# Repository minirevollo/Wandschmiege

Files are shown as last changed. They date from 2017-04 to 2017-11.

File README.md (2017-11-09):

## Anreisswerkzeug

Mess- und Anzeichenwerkzeug zum Verlegen von Parkett, Laminat und Bodenplatten etc.

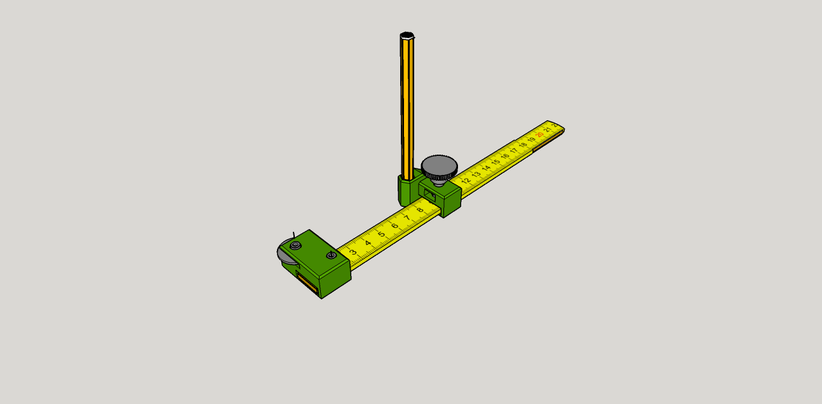
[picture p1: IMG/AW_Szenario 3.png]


Bestehend aus 3D-druckbaren Teilen und Standartelementen.

# Design #
Mit Sketchup konstruiert und als STL exportiert. Ziel war es ein Werkzeug zu erstellen, dass überwiegend mit Serienteilen zu produzieren ist und nur zwei Teile gedruckt werden müssen. Wer keinen 3D Drucker hat kommt einfach mal in den erfindergarden und wir helfen ihm weiter.
# Druck #
Slicen mit Craftware und Druck auf einem Craftbot
# Produktionsort #

[www.erfindergarden.de](http://www.erfindergarden.de)  , das Fab Lab in der Au - München
# Funktion #
Die Funktion ist auf dem folgenden Bild erklärt:

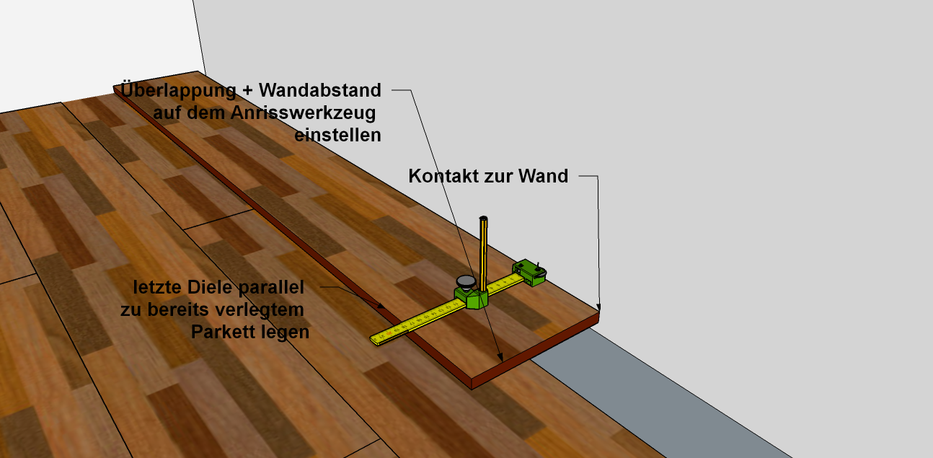
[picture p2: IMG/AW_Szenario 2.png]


Man legt die letzte Diele parallel zur vorletzten Diele und verschiebt sie dann parallel bis an die Wand. Dann misst man die Überlappung der beiden Dielen. Zu dieser Überlappung rechnet man noch den gewünschten Wandabstand (in der Regel 1 cm). Diese Summe stellt man auf dem Werkzeug ein. Nun fährt man mit dem Anreisser im rechten Winkel zur Wand an der Wand entlang und zeichnet dabei die Schnittlinie mit einem Bleistift an. Jetzt muss man nur noch mit einer Stichsäge und ruhiger Hand an der Linie entlang schneiden und die lezte Diele passt perfekt.

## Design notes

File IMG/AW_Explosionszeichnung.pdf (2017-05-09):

# Anreisswerkzeug

# ein Produkt aus dem erfindergarden (https://www.erfindergarden.de/) von

Andreas Reheis 2017 ,

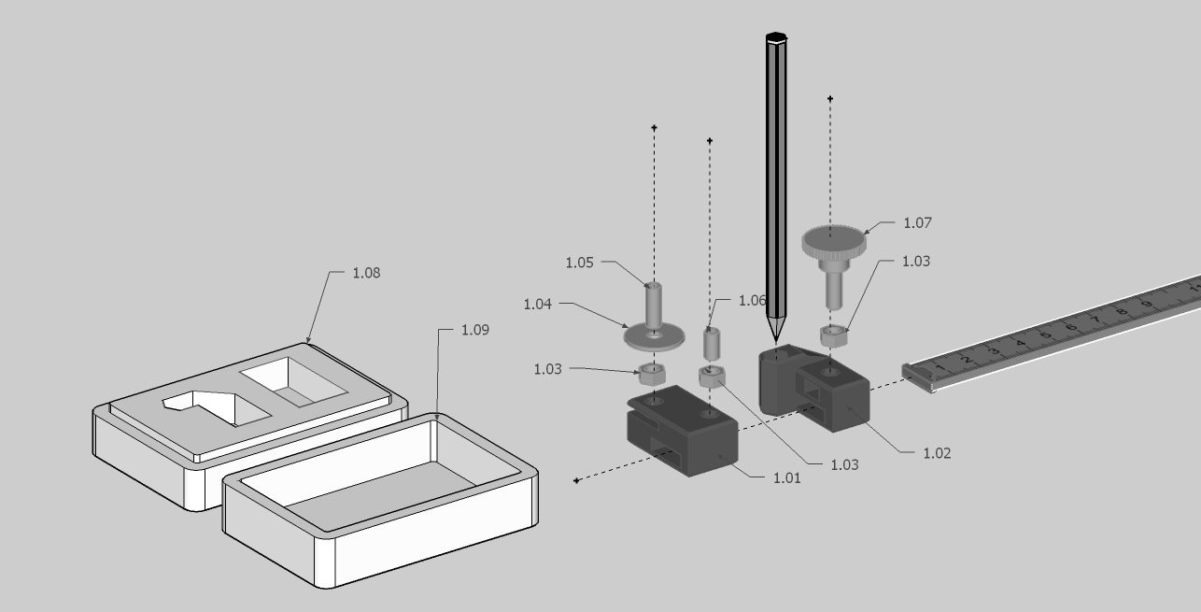
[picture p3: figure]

Teile Nr. | Beschreibung | Bezugsquelle
1.01 | Rollenhalter | Github (https://github.com/minirevollo/Wandschmiege/blob/master/AW_Rollenhalter%20v5.stl)
1.02 | Stifthalter | Github (https://github.com/minirevollo/Wandschmiege/blob/master/AW_Stifthalter_v5.stl)
1.03 | Mutter M5 | https://www.normschrauben.de/muttern/sechskant-muttern/sechskantmutter-sechskantmuttern-stahl-zn-934.html
1.04 | Beilagscheibe 20/6 | https://www.normschrauben.de/scheiben-beilagscheiben/din-9021-grosse-scheiben/scheiben-beilagscheiben-din-9021-verzinkt.html
1.05 | Madenschraube M5-15 | https://www.normschrauben.de/gewindestifte/gewindestifte-madenschrauben-din-914-stahl-blank.html
1.06 | Madenschraube M5-10 | https://www.normschrauben.de/gewindestifte/gewindestifte-madenschrauben-din-914-stahl-blank.html
1.07 | Rendelschraube M5-12 | https://www.befestigungsfuchs.de/befestigungstechnik/schrauben/raendelschrauben/10-raendelschrauben-m5-x-16-mm---din-653---niedrige-form---edelstahl-a1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
1.08 | Case Unterteil | Github (https://github.com/minirevollo/Wandschmiege/blob/master/AW_Case_Unterteil.stl)
1.09 | Case Oberteil | Github (https://github.com/minirevollo/Wandschmiege/blob/master/AW_Case_Oberteil.stl)

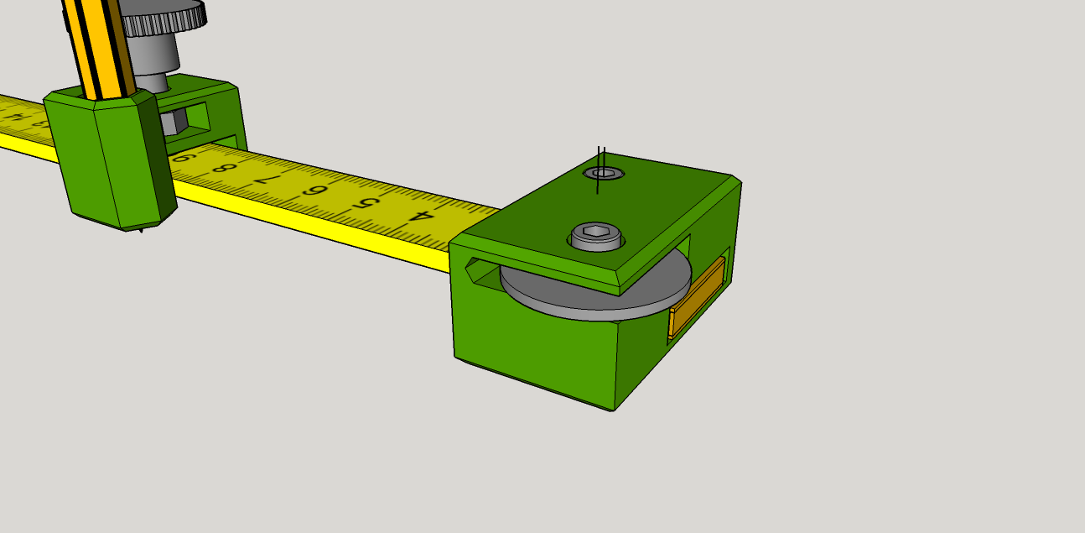
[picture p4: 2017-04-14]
IMG/AW_Szenario 4.png

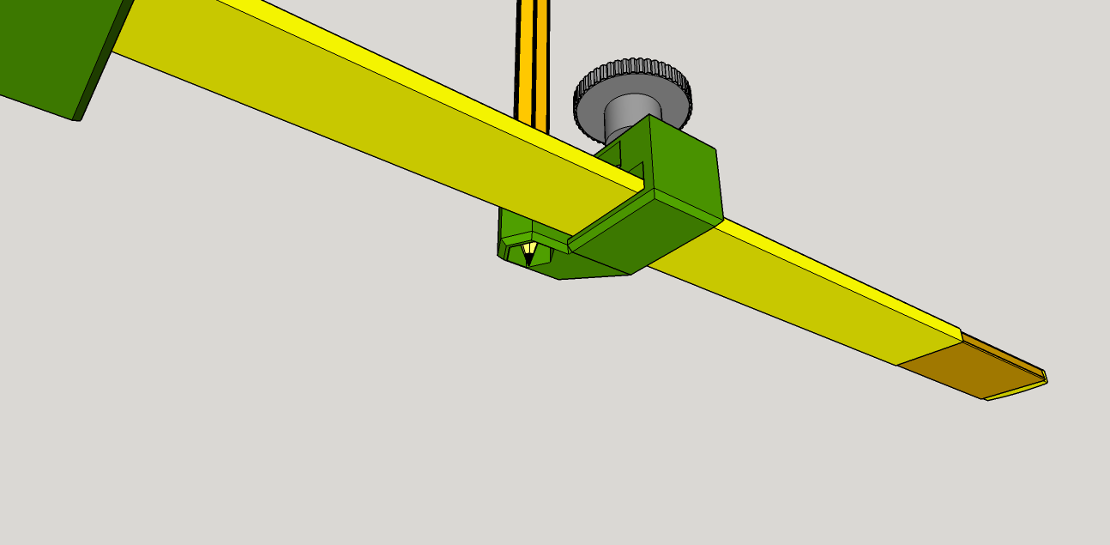
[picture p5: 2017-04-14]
IMG/AW_Szenario 5.png

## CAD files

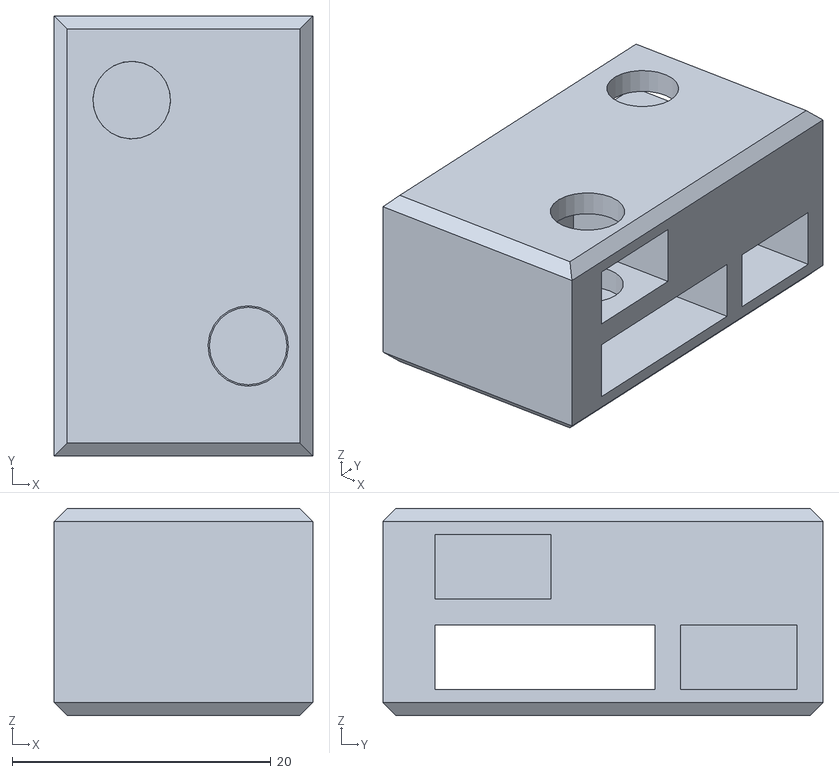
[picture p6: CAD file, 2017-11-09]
3D/AW_Rollenhalter v5.stl
20.0 x 34.0 x 16.0

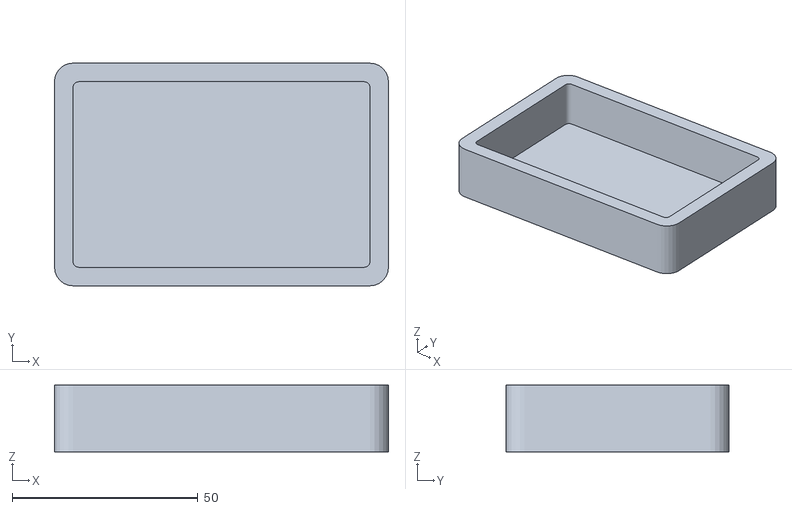
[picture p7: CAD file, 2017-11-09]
3D/AW_Case_Oberteil.stl
90.0 x 60.0 x 18.0

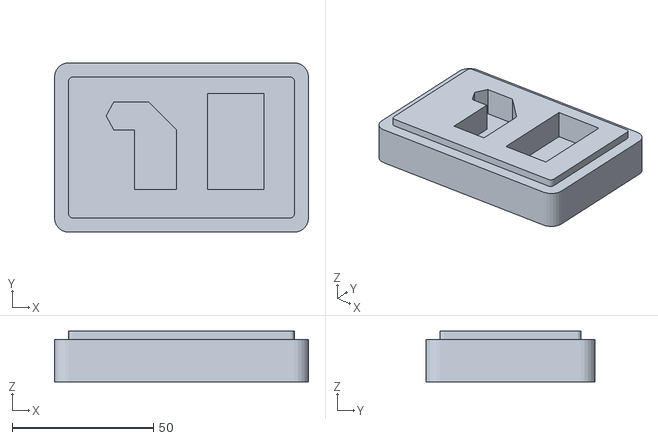
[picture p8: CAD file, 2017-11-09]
3D/AW_Case_Unterteil.stl
90.0 x 60.0 x 18.0

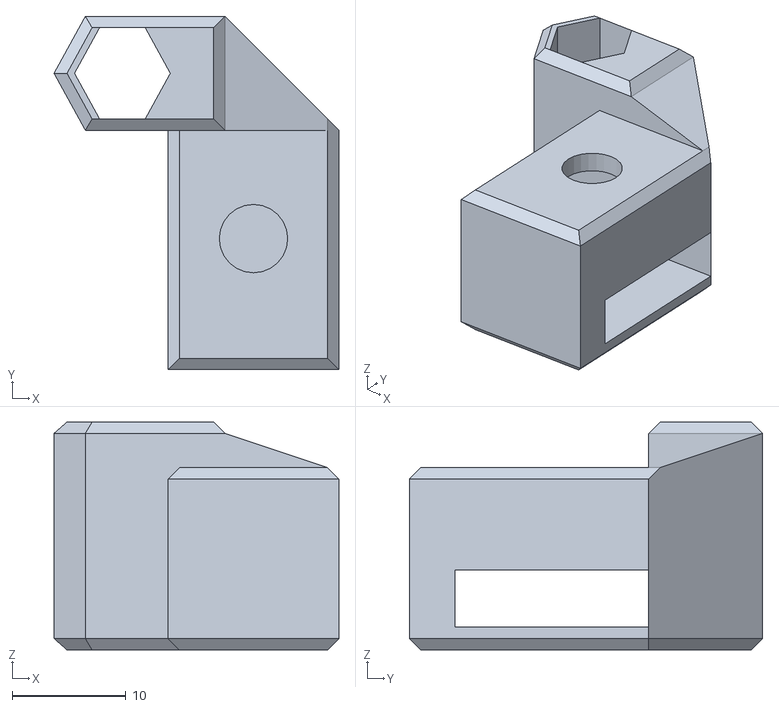
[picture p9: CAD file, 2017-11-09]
3D/AW_Stifthalter_v5.stl
25.0 x 31.0 x 20.0
